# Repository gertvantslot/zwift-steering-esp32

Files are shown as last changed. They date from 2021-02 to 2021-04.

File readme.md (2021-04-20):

DIY Zwift Steering with ESP32
=============================

> Warning  
> ------
>
> __Work in progress__

Build a Zwift steering device using an ESP32 (development board).

## Software / Firmware
Target hardware is: MH-ET Live (ESP32 Development board)

## Hardware
3D printed. Modified STL files from Keith files.

Hardware list:
- MH-ET Live  
  https://docs.platformio.org/en/latest/boards/espressif32/mhetesp32devkit.html  
  [PinOut](hardware/img/1499504017768-1pinmap.jpg)

## Features

* BLE connection to Zwift
* Smoothing of measured data
* Automatic detection of measured interval  
  Not constructing the device, it is impossible to mount the potentiometer always in exact the same position. This feature will detect the highest & lowest measured values.
* Automatic correction of the center   
  When the device is not completely centered on the floor, you get a steering error. This feature will automatically correct and makes sure you steer straight.

# Quick manual

1. Turn on steering device
2. Detect the steering range
   1. Steer maximum to the right for 10 seconds
   1. Steer maximum to the left for 10 seconds
   1. The device is calibrated now
3. Start Zwift, click on the Steer button and connect.
4. When using Zwift, if you notice there is an offset for steering straight. 
   * Keep your steer like you want to steer straight (0° angle).
   * After a few minutes this will become your zero angle.

References
----------

* https://github.com/kwakeham/zwift-steerer/
* https://sourceforge.net/projects/zwift-steering-esp32/

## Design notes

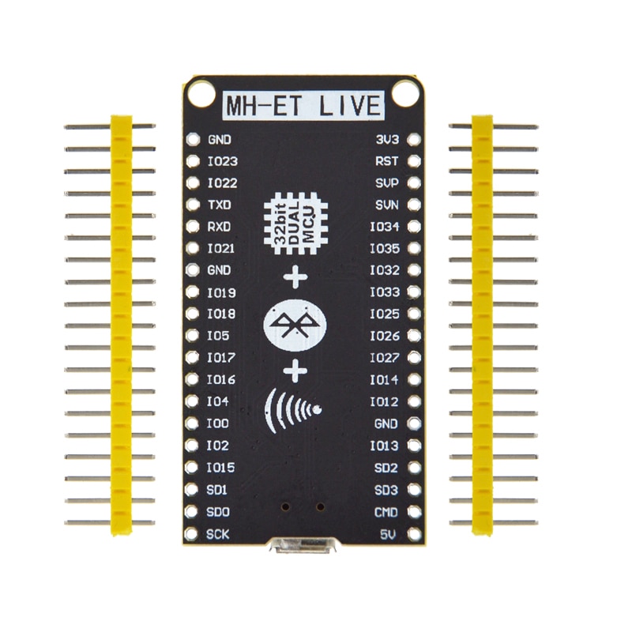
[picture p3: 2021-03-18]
hardware/img/esp32.jpg

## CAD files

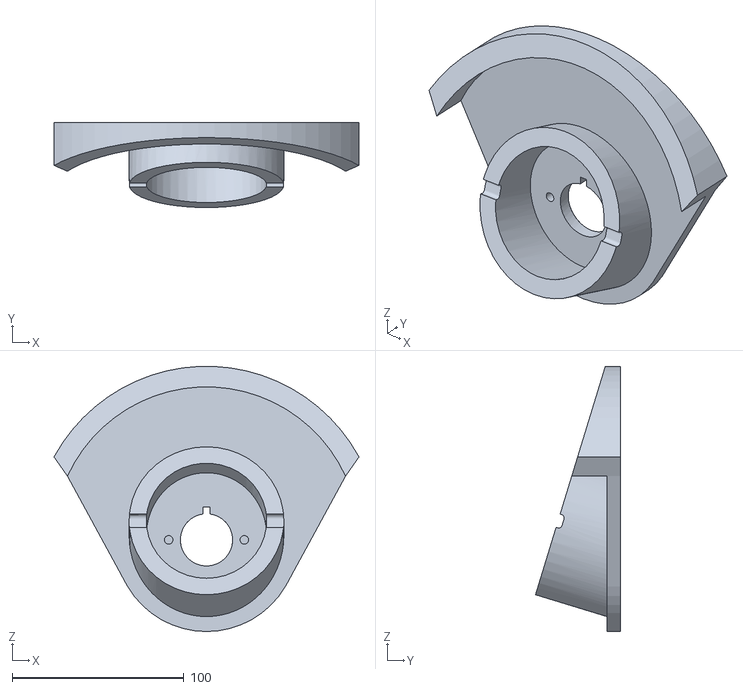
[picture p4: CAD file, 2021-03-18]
hardware/base-001/FlatBase-MKI.STL
177.5 x 49.5 x 154.2

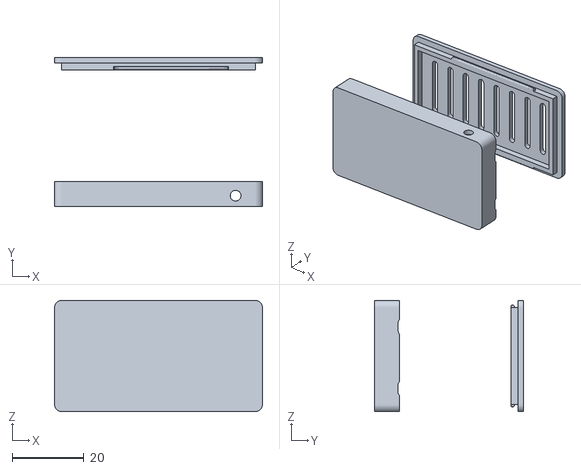
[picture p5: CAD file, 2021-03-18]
hardware/case-3/Case 003 v10.stl
58.0 x 41.5 x 31.0

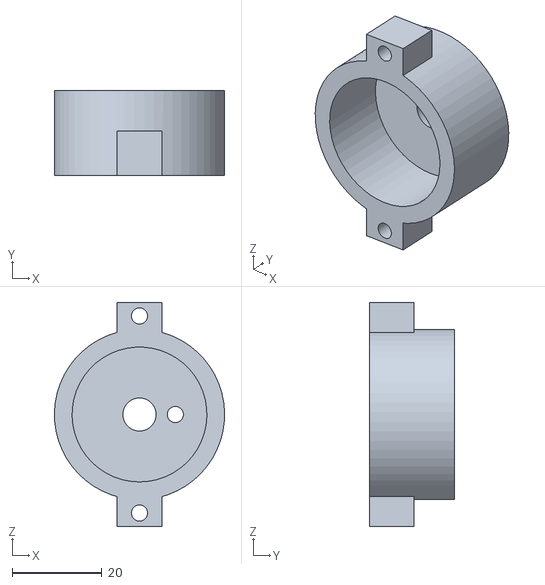
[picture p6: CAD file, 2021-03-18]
hardware/originals/pot-holder-MKI.STL
38.0 x 19.0 x 50.0

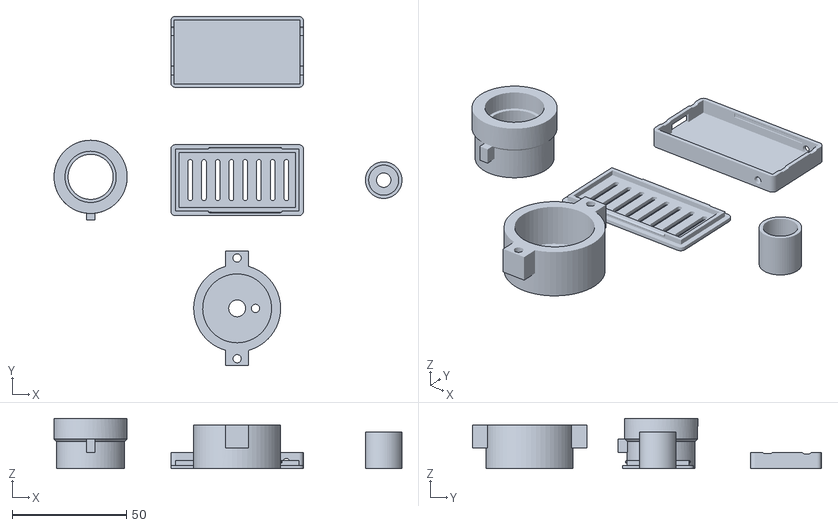
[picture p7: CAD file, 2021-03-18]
hardware/print-001/all.stl
152.0 x 152.5 x 22.0

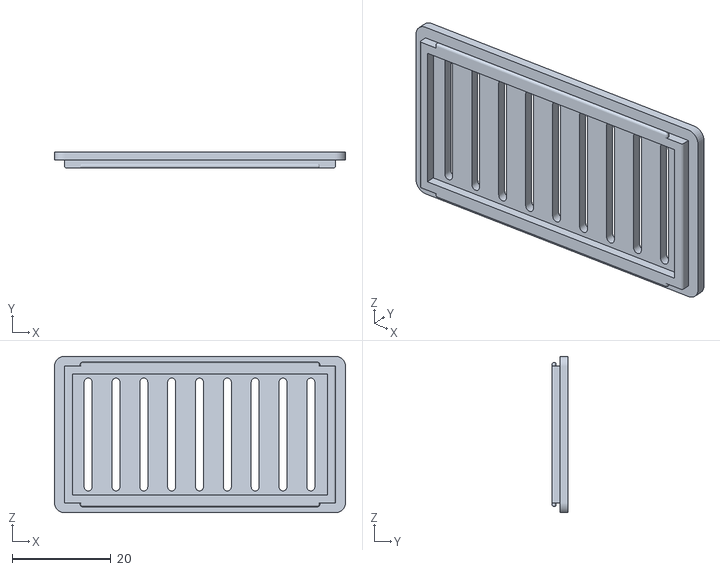
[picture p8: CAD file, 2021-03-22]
hardware/print-002/Case 004 v5 - top.stl
58.8 x 3.20 x 31.6

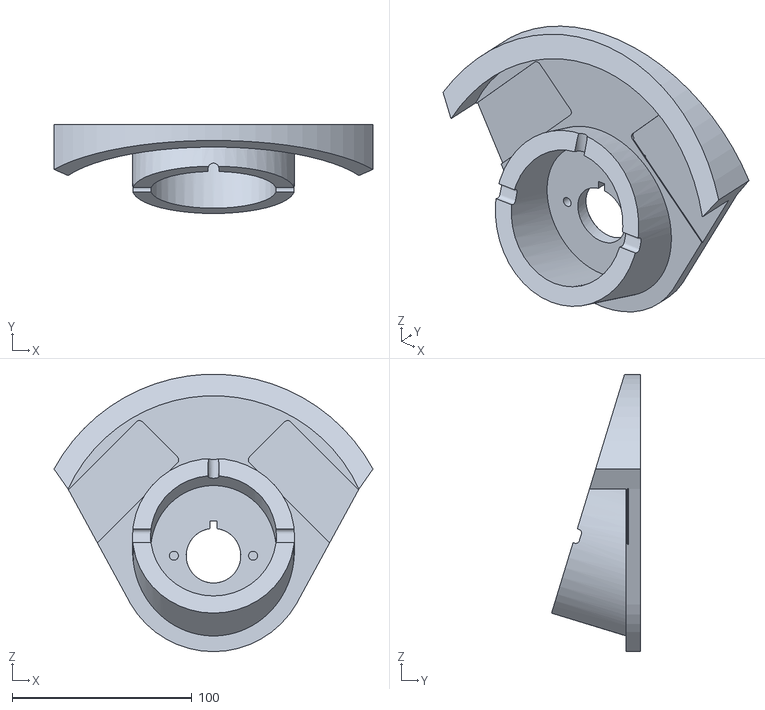
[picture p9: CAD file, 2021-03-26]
hardware/print-003/Flat v13.stl
177.4 x 49.5 x 154.2

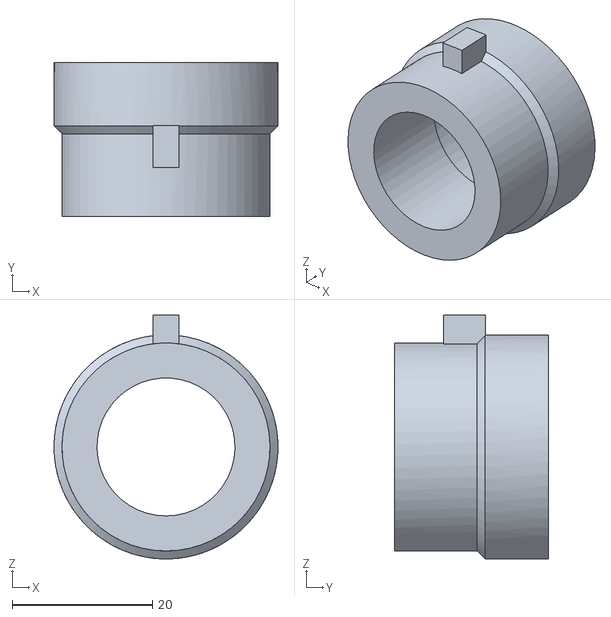
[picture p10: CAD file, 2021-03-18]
hardware/originals/Plug-MKI.STL
32.0 x 22.0 x 34.9

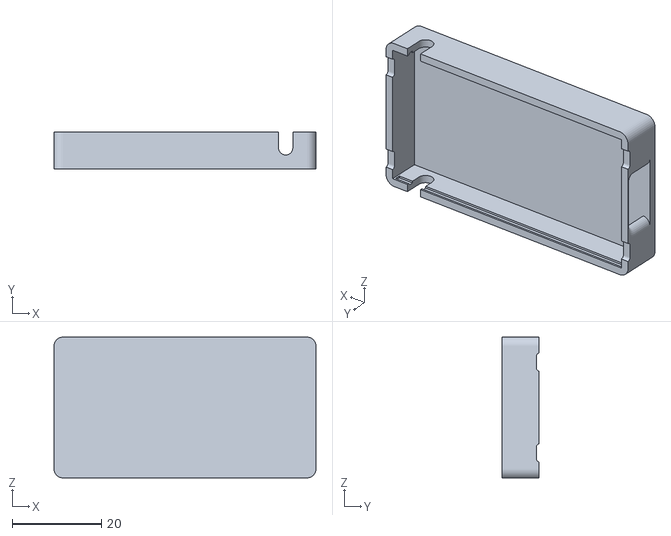
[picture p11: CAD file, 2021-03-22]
hardware/print-002/Case 004 v6 - bottom.stl
58.8 x 8.40 x 31.6

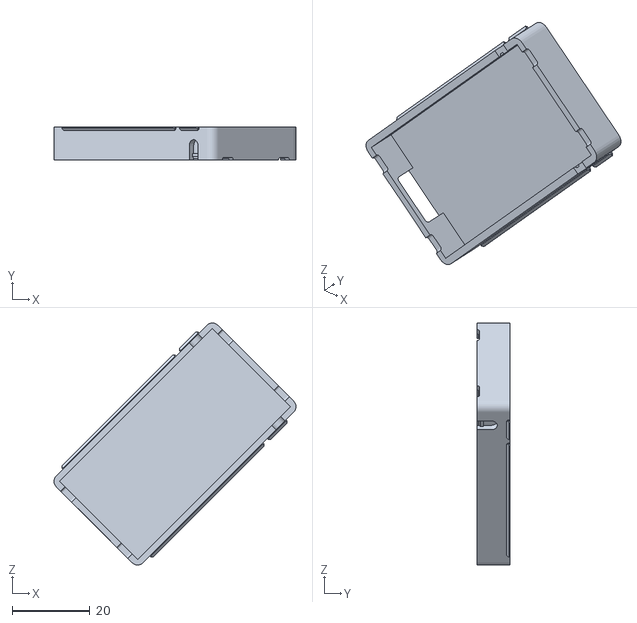
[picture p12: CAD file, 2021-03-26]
hardware/print-003/Box - voor montage in flat.stl
62.3 x 8.40 x 62.3

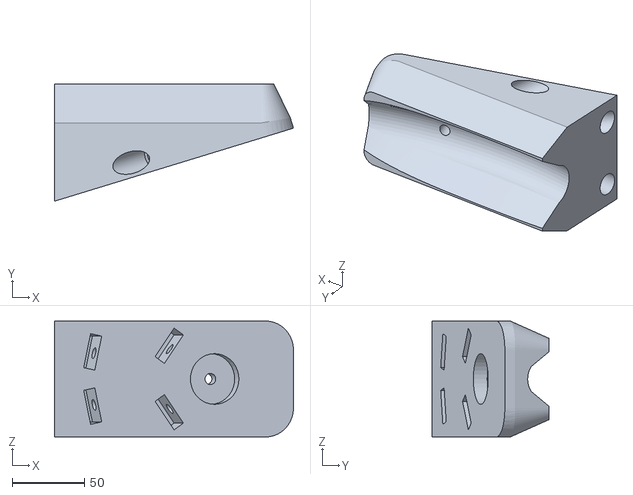
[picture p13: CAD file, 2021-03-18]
hardware/print-002/Swivel.STL
165.0 x 81.0 x 80.0

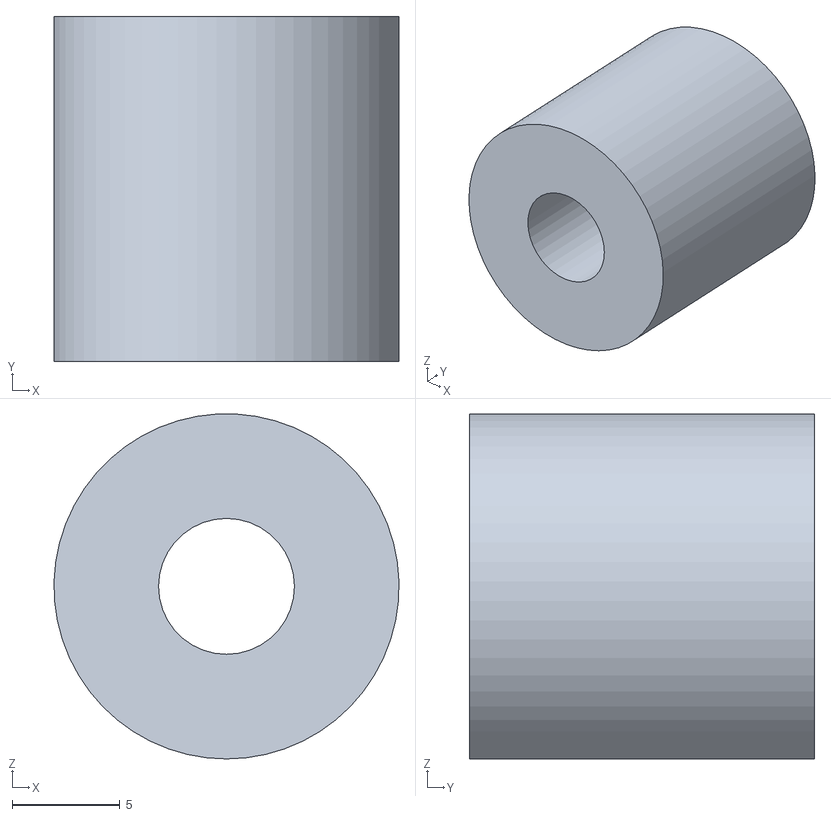
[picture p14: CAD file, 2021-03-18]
hardware/originals/Pot-Bolt-Adapter-MKI.STL
16.0 x 16.0 x 16.0

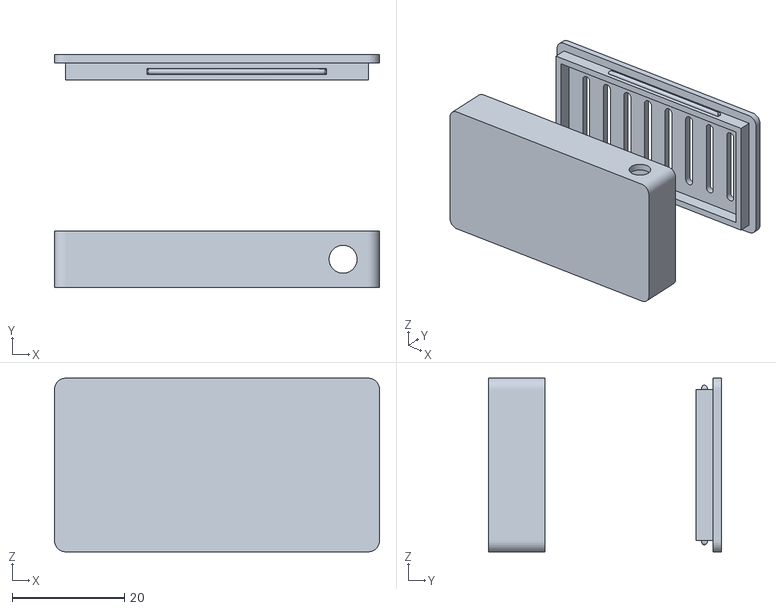
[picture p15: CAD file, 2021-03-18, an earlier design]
hardware/case-3/Case 003 v6.stl
58.0 x 41.5 x 31.0

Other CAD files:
hardware/case-3/Case 003 v9.stl
hardware/case-3/Case 003 v6.f3d
hardware/case-3/Case 003 v9.f3d

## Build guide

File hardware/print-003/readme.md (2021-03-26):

Print 003
=========

Box - voor montage in flat
--------------------------

Onderkant van doos, bijna zelfde als in Print-002, maar nu met klene uitsteeksels, zodat deze (ondersteboven) in de flat gemonteerd kan worden.

Steekt bij montage iets uit, maar anders krijg ik deze met deksel er niet goed onder, zonder de "flat" teveel te verzwakken.

**Printen:** Normale print instellingen. Komt geen kracht op.  
Deksel van Print-002 is te gebruiken, en zou nog steeds moeten passen. 

Flat v13
--------

"Flat" = onderste deel, aangepast zodat de Box er in geschoven kan worden.

**Printen:** Mag "grof" geprint worden, om printen te versnellen. Hier komt kracht op, (verticaal) door het wiel via de Swivel. Vulling 30% volgens Website.

Bovenkant moet ook redelijk "slijtvast" zijn. De rollagers komen hier op te rollen. Dit is de onderkant bij het printen. Daarom "natuurlijk" goed glad.

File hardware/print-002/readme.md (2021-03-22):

Case 004 v5 - bottom.stl // Case 004 v6 - bottom.stl
====================================================

Samengevoegd tot `CE5P_Case 004.3mf`

_Wat:_ Doosje. Moet straks in de voet worden geïntegreerd.

Test print, om te zien of alles past.

Nu Standard Quality.

Swivel.stl // CE5P_Swivel.3mf
=============================

_Wat:_ Bovenstuk van stuurinrichting.

Wanden moet redelijk sterk zijn, want er moeten bouten (M8) + rollagers in worden gedraaid. Geen trekkrachten. Wel verticale kracht.

Printen duurt lang (1 dag, 6 uur). Snelste is met onderkant liggend op het vlak. 

Krachten: Door het wiel, voornamelijk vertikaal. Daarom Cubic infill gekozen.

Nu ingesteld: Top & wall: 3mm. Infill 35%.

Nu Standard Quality. Maar ik denk dat Low Quality gaat goed genoeg zijn.

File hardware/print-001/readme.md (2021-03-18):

Te printen objecten
===================

Kleine objecten om eens te testen of het printen werkt.

Eigen ontwerp ESP32 Case. Later te integreren in de voet van het stuur, zodat de ESP32 beschermd zit.

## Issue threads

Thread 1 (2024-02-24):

No data received

usenetj23, 2024-02-24:
esp32 not visible on controls screen.  Connection possible using Power Source but after choosing this and  appering steering in controls in terminal monit: 'No  data received'

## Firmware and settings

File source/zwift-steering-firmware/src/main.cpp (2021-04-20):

/*

// Zwift steering code
// * PlatformIO
// * ESP32 - MH-ET Life: 
// - https://docs.platformio.org/en/latest/boards/espressif32/mhetesp32devkit.html 
// - https://forum.mhetlive.com/topic/2/mh-et-live-esp32-devkit


// Takes ADC reading from pin 36 and converts to an angle between -40 and +40 and transmits to Zwift via BLE

  //Based on BLE Arduino for ESP32 examples (Kolban et al.)
  //Keith Wakeham's explanation https://www.youtube.com/watch?v=BPVFjz5zD4g
  //Andy's demo code: https://github.com/fiveohhh/zwift-steerer/

  //Tested using Zwift on Android (Galaxy A5 2017)

    * Copyright 2020 Peter Everett
    * v1.0 Sep 2020 - Initial version
    * 
    * This work is licensed the GNU General Public License v3 (GPL-3)

  // =========================
  Gert van 't Slot
  v1 - februari 2021
  - Calibration mode
  - Use ADC 0

*/

#include <Arduino.h>
#include <math.h>

#include <BLE2902.h>
#include <BLEDevice.h>
#include <BLEServer.h>
#include <BLEUtils.h>

#include "settings.h"
#include "calibrate.h"

#define STEERING_DEVICE_UUID     "347b0001-7635-408b-8918-8ff3949ce592"
#define STEERING_ANGLE_CHAR_UUID "347b0030-7635-408b-8918-8ff3949ce592"  //notify
#define STEERING_RX_CHAR_UUID    "347b0031-7635-408b-8918-8ff3949ce592"  //write
#define STEERING_TX_CHAR_UUID    "347b0032-7635-408b-8918-8ff3949ce592"  //indicate

#define DELAY_HANDSHAKE 125
#define DELAY_HANDSHAKE2 250
#define DELAY_BLE_COOLDOWN 100
#define DELAY_BLINK 250

// Channel to use for PWM 
//  indicator on LED_BUILT_IN
#define CH_INDICATOR 15

// Timers
unsigned long timer_data = 0;
unsigned long timer_ble_cooldown = 0;
unsigned long timer_blink = 0;

bool deviceConnected = false;
bool oldDeviceConnected = false;
bool authenticated = false;

boolean measurementsReceived = false;
float angle = 0;
const float angle_average = 250; // Number of measurements to average
                                 // Higher = reduce noise, but slower steering

uint16_t potValue_range = potValue_max - potValue_min;

#ifdef DEBUG_TO_SERIAL
    #define pln(X) Serial.println(X)
    #define p(X) Serial.print(X)
#else
    #define pln(X)
    #define p(X)
#endif

#ifdef ANGLE_CALIBRATE
    // Minimum and maximum values, make sure they are overwritten on first pass
    uint16_t pot_measured_min = UINT16_MAX;
    uint16_t pot_measured_max = 0;
    float angle_measured_min = 180.0f;
    float angle_measured_max = -180;

    unsigned long timer_calibrate = 0;
    #define DELAY_CALIBRATE 5000
#endif

#ifdef AUTO_CENTER

    #define AUTOCENTER_SIZE 1024
    #define AUTOCENTER_RESOLUTION 4
    #define AUTOCENTER_EDGE 0x10

    #ifdef AUTO_CENTER_DEBUG
        #define AUTOCENTER_INTERVAL 30000
        #define AUTOCENTER_MAX_ADJUST 0x40
    #else
        #define AUTOCENTER_INTERVAL 60000
        #define AUTOCENTER_MAX_ADJUST 0x20
    #endif

    uint64_t autoCenterMeasurements[AUTOCENTER_SIZE];
    int autoCenterCenter = (potValue_min + potValue_max) / 2; // Initialize to center
    unsigned long autoCenterLastTime = 0;

    void autoCenterStore(uint16_t potVal) {
        // Only when active in the game
        if (!measurementsReceived) return;
        #ifndef AUTO_CENTER_DEBUG
            if (!authenticated) return;
        #endif

        int index = potVal / AUTOCENTER_RESOLUTION;
        autoCenterMeasurements[index]++;
    }

    void autoCenterClear() {
        for(int i = 0; i < AUTOCENTER_SIZE; i++) {
            autoCenterMeasurements[i] = 0;
        }
    }

    // https://en.wikipedia.org/wiki/Savitzky%E2%80%93Golay_filter
    // https://en.wikipedia.org/wiki/Savitzky%E2%80%93Golay_filter#/media/File:Lorentzian_and_derivative.gif
    // http://www.statistics4u.info/fundstat_eng/cc_savgol_coeff.html
    #define SG_1ST_SIZE 25
    #define SG_1ST_NORM 1300.0F

    #define SG_1ST_SIZE_RNG ((SG_1ST_SIZE - 1) / 2)
    // Coefficient, for 1st derivative : a(i) = i  
    float autoCenterSmoothedFirstDerivative(uint16_t index) {
        float sum = 0;
        for(int i = -SG_1ST_SIZE_RNG; i <= SG_1ST_SIZE_RNG; i++) {
            float sg_coeff = i; // See http://www.statistics4u.info/fundstat_eng/cc_savgol_coeff.html 
            sum += (float)(autoCenterMeasurements[index + i]) * sg_coeff;
        }
        return sum / SG_1ST_NORM;
    }

    uint16_t autoCenterMidPoint() {
        // Get the index of the value that is used the most
        // this will be the direction the user has steered the most of the time
        // and we hope, this will be straight
        // 
        // Method: 
        // For every point, get the (smoothed) 1st derivative
        // Get the index of the highest and lowest value
        // The midpoint will be center between these two
        int index_max = 0;
        int index_min = 0;
        float max = std::numeric_limits<float>::min();
        float min = std::numeric_limits<float>::max();

        bool containsData = false;

        const int edgeMin = (potValue_min / AUTOCENTER_RESOLUTION) + AUTOCENTER_EDGE;
        const int edgeMax = (potValue_max / AUTOCENTER_RESOLUTION) - AUTOCENTER_EDGE;

        p("AutoCenter: Scanning for midpoint [");
        p(edgeMin * AUTOCENTER_RESOLUTION);
        p(" , ");
        p(edgeMax * AUTOCENTER_RESOLUTION);
        pln("]");

        for(int i = edgeMin; i < edgeMax; i++) {
            if (autoCenterMeasurements[i] > 100) {
                containsData = true;
            }
            float smoothed = autoCenterSmoothedFirstDerivative(i);

            if (smoothed > max) {
                max = smoothed;
                index_max = i;
            }            
            if (smoothed < min) {
                min = smoothed;
                index_min = i;
            }
        }

        if (!containsData) {
            // Nothing measured, or steer is on maximum range
            pln("AutoCenter: No data: Midpoint not recalculated");
            return autoCenterCenter; // Current center
        }

        int midPoint = (index_min + index_max) / 2;
        
        p("AutoCenter: Midpoint recalculated: ");
        p(autoCenterCenter);
        p(" => ");
        pln(midPoint * AUTOCENTER_RESOLUTION);

        return (uint16_t)(midPoint * AUTOCENTER_RESOLUTION);
    }

    #ifdef AUTO_CENTER_DEBUG
    void autoCenterPrintGraph() {
        // Graph
        const uint32_t lines = 32;
        const uint32_t values_per_line = AUTOCENTER_SIZE / 32;
        uint64_t values[lines];

        uint64_t max = 0;

        // Dermine scale
        for(int i = 0; i < lines; i++) {
            uint64_t sum = 0;
            for(int j = 0; j < values_per_line; j++) {
                sum += autoCenterMeasurements[(i * values_per_line) + j];
            }
            values[i] = sum;
            if (sum > max) {
                max = sum;
            }
        }

        // float scale = 60.0 / max;

        for(int i = 0; i < lines; i++) {
            p(i * values_per_line * AUTOCENTER_RESOLUTION);
            p(" = ");
            pln(values[i]);
        }
    }
    #endif

    // Calibrate - Determine new midpoint, only once overy X seconds
    void autoCenterCalibrate() {
        if (millis() - autoCenterLastTime < AUTOCENTER_INTERVAL) return;
        autoCenterLastTime = millis();

        pln("AutoCenter: Calibration started");

        #ifdef AUTO_CENTER_DEBUG
        autoCenterPrintGraph();
        #endif

        int newCenter = autoCenterMidPoint();
        if (abs(newCenter - autoCenterCenter) < AUTOCENTER_MAX_ADJUST) {
            autoCenterCenter = newCenter;
        } else {
            if (newCenter < autoCenterCenter) {
                autoCenterCenter -= AUTOCENTER_MAX_ADJUST;
            } else {
                autoCenterCenter += AUTOCENTER_MAX_ADJUST;
            }
        }

        p("Active midpoint: ");
        pln(autoCenterCenter);

        autoCenterClear();
    }

    float autoCenterCorrectedAngle(uint16_t potVal) {
        if (potVal == autoCenterCenter) return 0.0F;
        if (potVal < autoCenterCenter) {
            // left of center = positive value
            // scale from potValue_min - autoCenterCenter === -zwift_angle_min° - 0°

            float range = autoCenterCenter - potValue_min;
            float retVal = ((float)autoCenterCenter - (float)potVal) / range * zwift_angle_sensitivity;
            #ifdef xAUTO_CENTER_DEBUG
            p("AutoCenter: Corrected value: L: ");
            p(potVal);
            p(" => ");
            p(retVal);
            pln();
            #endif
            return retVal;
        } else {
            // right of center = negative value
            float range = potValue_max - autoCenterCenter;
            float retVal = ((float)autoCenterCenter - (float)potVal) / range * zwift_angle_sensitivity;
            #ifdef xAUTO_CENTER_DEBUG
            p("AutoCenter: Corrected value: R: ");
            p(potVal);
            p(" => ");
            p(retVal);
            pln();
            #endif
            return retVal;
        }
    }

#endif

// define the return values to Zwift
const float zwift_angle_min = -zwift_angle_sensitivity; 
const float zwift_angle_max =  zwift_angle_sensitivity; 
const float zwift_angle_range = zwift_angle_max - zwift_angle_min; // 40 - (-40) = 80
float zwift_angle_factor = zwift_angle_range / (float)potValue_range;

int FF = 0xFF;
uint8_t authChallenge[4] = {0x03, 0x10, 0xff, 0xff};
uint8_t authSuccess[3] = {0x03, 0x11, 0xff};

BLEServer* pServer = NULL;
BLECharacteristic* pAngle = NULL;
BLECharacteristic* pRx = NULL;
BLECharacteristic* pTx = NULL;

BLEAdvertising* pAdvertising;

class MyServerCallbacks : public BLEServerCallbacks {
    void onConnect(BLEServer* pServer) {
        deviceConnected = true;
    };

    void onDisconnect(BLEServer* pServer) {
        deviceConnected = false;
    }
};

float readAngle() {
    int potVal = analogRead(POT);
    if (potVal < potValue_error) {
        // Too low for a correct measurement
        return 0.0;
    }
    
    #ifdef xAUTO_CENTER_DEBUG
        potVal = (4096 / 4) + sin(millis() / 60000.0) * 300;
    #endif
    float retVal = 0.0;

    if (!measurementsReceived && potVal > potValue_error) {
        // We have input
        pln("Looks like the system is connected");
        measurementsReceived = true;
    }

    #ifdef AUTO_CALIBRATE

    if (measurementsReceived) {
        if (potVal < potValue_min) {
            potValue_min -= 2; // Decrease, but not too much (error measurements)
            #ifdef AUTO_CENTER
            autoCenterCenter--;
            #endif
            potValue_range = potValue_max - potValue_min;
            zwift_angle_factor = zwift_angle_range / (float)potValue_range;
            pln("AutoCalibrate: <<< Angle Min corrected");
        }
        if (potVal > potValue_max) {
            potValue_max += 2;
            #ifdef AUTO_CENTER
              autoCenterCenter++;
            #endif
            potValue_range = potValue_max - potValue_min;
            zwift_angle_factor = zwift_angle_range / (float)potValue_range;
            pln("AutoCalibrate: >>> Angle Max corrected");
        }
    }

    #endif

    #ifdef AUTO_CENTER 
        autoCenterStore(potVal);
    #endif

    if (potVal < potValue_min) {
        retVal = zwift_angle_min;
    } else {
        if (potVal > potValue_max) {
            retVal = zwift_angle_max;
        } else {
            #ifdef AUTO_CENTER 
            retVal = autoCenterCorrectedAngle(potVal);
            #else
            retVal = zwift_angle_min + (potVal - potValue_min) * zwift_angle_factor;
            #endif
        }
    }

    // Correct for direction
    retVal *= zwift_angle_direction;

    #ifdef ANGLE_CALIBRATE

    if (millis() - timer_calibrate > DELAY_CALIBRATE) {
        timer_calibrate = millis();
        if (potVal < pot_measured_min) pot_measured_min = potVal;
        if (potVal > pot_measured_max) pot_measured_max = potVal;
        if (retVal < angle_measured_min) angle_measured_min = retVal;
        if (retVal > angle_measured_max) angle_measured_max = retVal;

        p("** ");
        p(potVal);
        p(" = ");
        p(retVal);

        p("  - Minimum values: ");
        p(pot_measured_min);
        p(" - ");
        p(angle_measured_min);

        p("  - Maximum values: ");
        p(pot_measured_max);
        p(" - ");
        p(angle_measured_max);
        pln();
    }
    #endif

    return retVal;
}

void handleIndicatorLight() {
    if (millis() - timer_blink < DELAY_BLINK) {
        return;
    }
    timer_blink = millis();

    if (deviceConnected && authenticated) {
        if (!measurementsReceived) {
            // Do some blinking
            ledcWrite(CH_INDICATOR, 255 - ((millis() / DELAY_BLINK) % 4) * 24);
        } else {
            ledcWrite(CH_INDICATOR, map((int)angle, -41, 40, 0, 255));
        }
    } else {
        ledcWrite(CH_INDICATOR, 255 - ((millis() / DELAY_BLINK) % 2) * 64);
    }
}

void sendAngleToZwift(float angle) {
    //Connected to Zwift so read the potentiometer and start transmitting the angle
    pAngle->setValue(angle);
    pAngle->notify();
}

void authenticateDevice() {
    //Not connected to Zwift so start the connectin process
    pTx->setValue(FF);
    pTx->indicate();
    //Do the handshaking
    std::string rxValue = pRx->getValue();
    if (rxValue.length() == 0) {
        pln("No data received");
        delay(DELAY_HANDSHAKE);
    } else {
        pln("Handshaking....");
        if (rxValue[0] == 0x03 && rxValue[1] == 0x10) {
            delay(DELAY_HANDSHAKE);
            //send 0x0310FFFF (the last two octets can be anything)
            pTx->setValue(authChallenge, 4);
            pTx->indicate();
            //Zwift will now send 4 bytes as a response, which start with 0x3111
            //We don't really care what it is as long as we get a response
            delay(DELAY_HANDSHAKE);
            rxValue = pRx->getValue();
            if (rxValue.length() == 4) {
                //connected, so send 0x0311ff
                delay(DELAY_HANDSHAKE2);
                pTx->setValue(authSuccess, 3);
                pTx->indicate();
                authenticated = true;
                pln("Success!");
            }
        }
    }
}

void setup() {
    //setup pins for Pot
    pinMode(POT, INPUT);
    pinMode(LED_BUILTIN, OUTPUT);
    digitalWrite(LED_BUILTIN, HIGH);

    #ifdef DEBUG_TO_SERIAL
        Serial.begin(115200);
    #endif

    //Setup BLE
    pln("Creating BLE server...");
    BLEDevice::init(NAME);

    // Create the BLE Server
    pServer = BLEDevice::createServer();
    pServer->setCallbacks(new MyServerCallbacks());

    // Create the BLE Service
    pln("Define service...");
    BLEService* pService = pServer->createService(STEERING_DEVICE_UUID);

    // Create BLE Characteristics
    pln("Define characteristics");

    pTx = pService->createCharacteristic(STEERING_TX_CHAR_UUID, BLECharacteristic::PROPERTY_INDICATE | BLECharacteristic::PROPERTY_READ);
    pTx->addDescriptor(new BLE2902());
    pRx = pService->createCharacteristic(STEERING_RX_CHAR_UUID, BLECharacteristic::PROPERTY_WRITE);
    pRx->addDescriptor(new BLE2902());
    pAngle = pService->createCharacteristic(STEERING_ANGLE_CHAR_UUID, BLECharacteristic::PROPERTY_NOTIFY);
    pAngle->addDescriptor(new BLE2902());

    // Start the service
    pln("Staring BLE service...");
    pService->start();

    // Start advertising
    // Zwift only shows the steering button when the service is advertised
    pln("Define the advertiser...");
    pAdvertising = BLEDevice::getAdvertising();
    pAdvertising->setScanResponse(true);
    pAdvertising->addServiceUUID(STEERING_DEVICE_UUID);
    pAdvertising->setMinPreferred(0x06);  // set value to 0x00 to not advertise this parameter
    pln("Starting advertiser...");
    BLEDevice::startAdvertising();
    pln("Waiting a client connection to notify...");

    // Use LED_BUILTIN to give feedback
    ledcSetup(CH_INDICATOR, 5000, 8);
    ledcAttachPin(LED_BUILTIN, CH_INDICATOR);
}

void loop() {
    // Read angle, reduce noise
    angle += (readAngle() - angle) / angle_average;

    #ifdef AUTO_CENTER
        autoCenterCalibrate();
    #endif

    handleIndicatorLight();

    // small interval so BLE stack doesn't get overloaded
    if (millis() - timer_ble_cooldown > DELAY_BLE_COOLDOWN) {
        timer_ble_cooldown = millis();
        
        if (deviceConnected) {
            if (authenticated) {
                sendAngleToZwift(angle);
            } else {
                authenticateDevice();
            }
        }
    }

    // disconnecting
    if (!deviceConnected && oldDeviceConnected) {
        delay(DELAY_HANDSHAKE2);   // give the bluetooth stack the chance to get things ready
        pServer->startAdvertising();  // restart advertising
        pln("Nothing connected, start advertising");
        oldDeviceConnected = deviceConnected;
    }
    // connecting
    if (deviceConnected && !oldDeviceConnected) {
        oldDeviceConnected = deviceConnected;
        pln("Connecting...");
    }
}

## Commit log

2021-03-18 3D models
    [Case 003 v10.stl, Case 003 v6.f3d, Case 003 v6.stl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]
2021-03-18 Alle objecten in één STL
    [all.stl]
2021-03-22 Print Test 2
    [CE5P_Case 004.3mf, CE5P_Swivel.3mf, Case 004 v5 - top.stl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]
2021-03-26 Derde print
    [Box - voor montage in flat.stl, CE5P_Box - voor montage in flat.3mf, CE5P_Flat v13.3mf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]
2021-04-06 Calibration mode
2021-04-20 Automatic center of steering
2021-04-20 Cleanup binaries
    [CE5P_Box - voor montage in flat.3mf, CE5P_Case 004.3mf, CE5P_Flat v13.3mf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]
